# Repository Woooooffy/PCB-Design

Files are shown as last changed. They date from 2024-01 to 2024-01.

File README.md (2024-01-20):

# PCB-Design
# Contains my project files
# Hug-sensing IoT plush: a pair of plushies that detects hugs on one end and triggers response in the other. Inspired by Becky and Xyla's project https://beckystern.com/2023/11/27/hug-sensing-iot-parihug-toy-w-xyla-foxlin/ and part of the MIT 2024 PCB design class

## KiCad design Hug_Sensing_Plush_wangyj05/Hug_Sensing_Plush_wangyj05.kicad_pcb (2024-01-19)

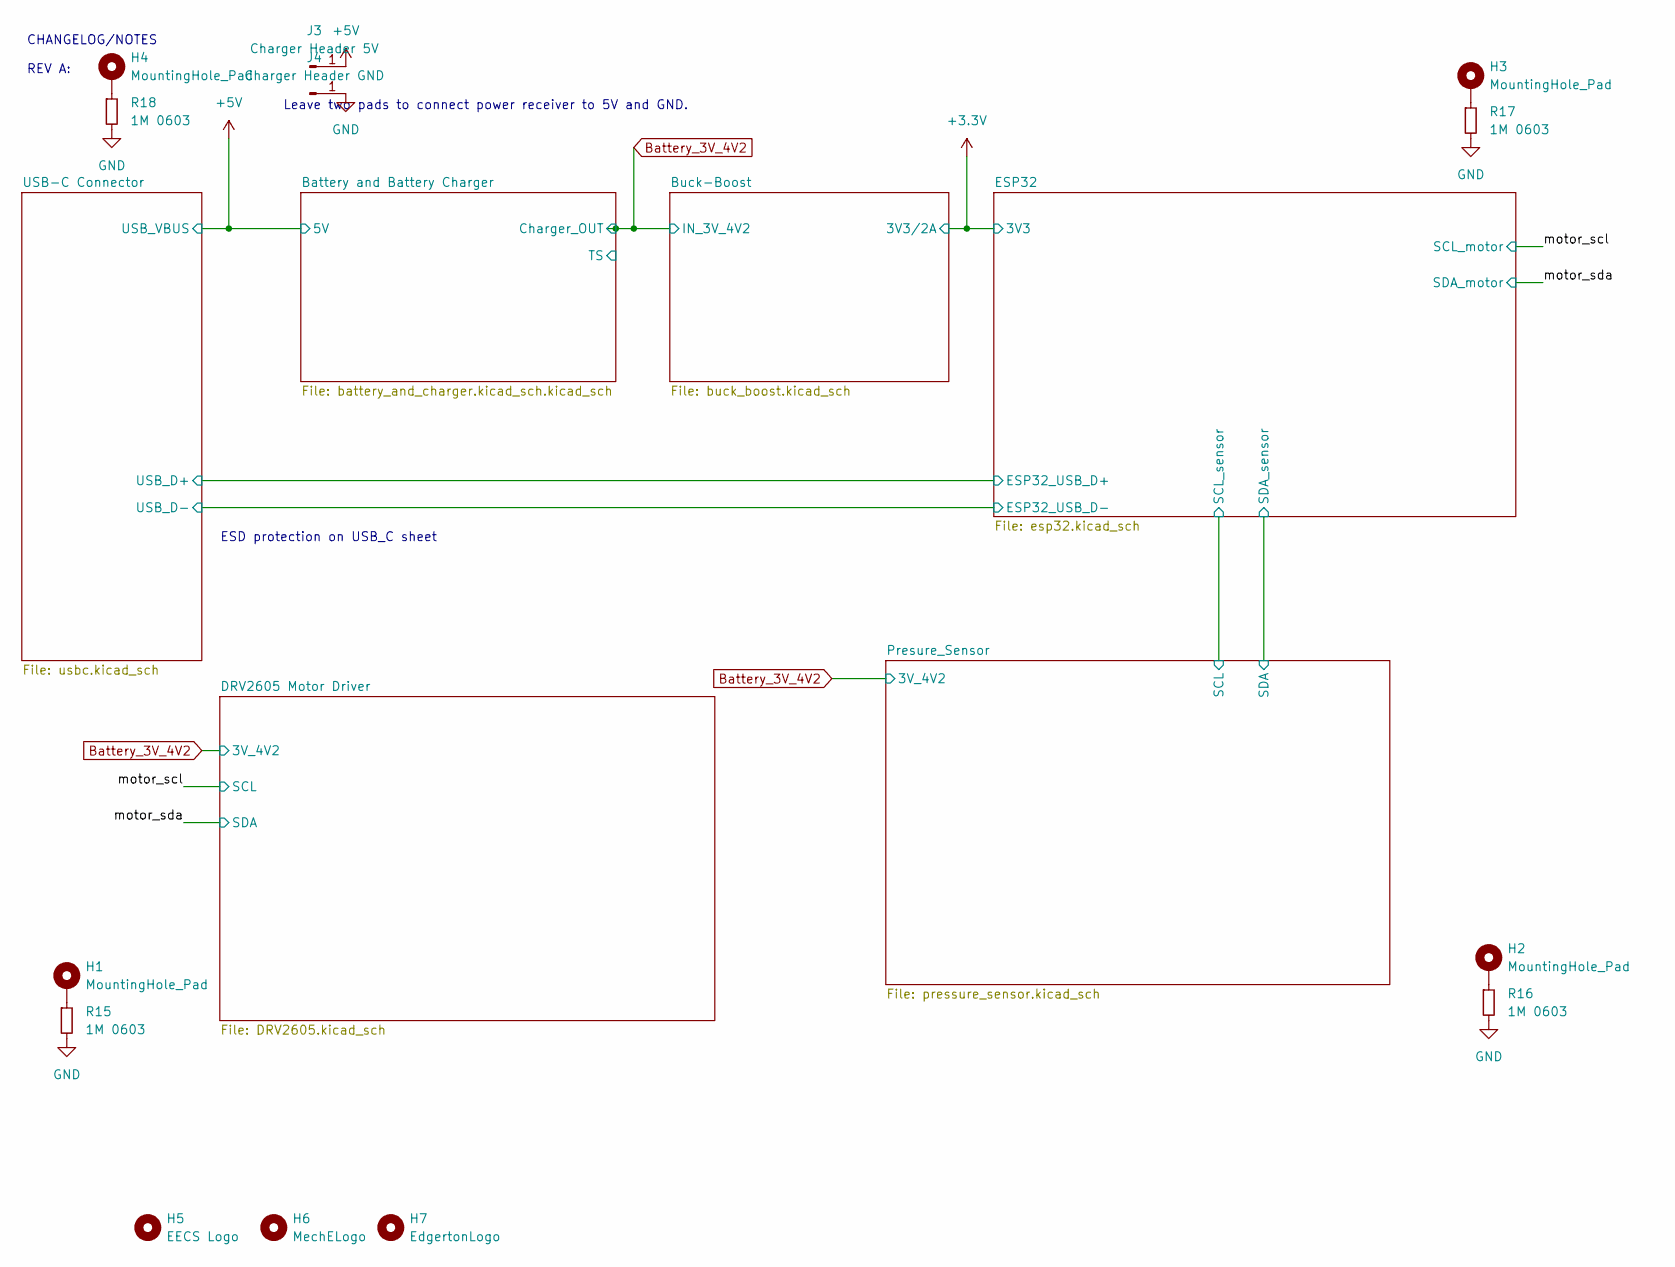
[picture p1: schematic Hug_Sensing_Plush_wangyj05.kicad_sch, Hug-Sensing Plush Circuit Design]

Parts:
H1, H2, H3, H4: MountingHole_Pad; MountingHole_2.2mm_M2_DIN965_Pad
H5: EECS Logo; EECSLogo
H6: MechELogo
H7: EdgertonLogo
J3: Charger Header 5V; SolderWirePad_1x01_SMD_1x2mm
J4: Charger Header GND; SolderWirePad_1x01_SMD_1x2mm
R15, R16, R17, R18: 1M 0603; R_0603_1608Metric_Pad0.98x0.95mm_HandSolder; MPN CRCW06031M00JNEAC; Digikey PN 541-CRCW06031M00JNEACCT-ND

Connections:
+5V: J3.1; also elsewhere on the board
GND: J4.1, R15.2, R16.2, R17.2, R18.2; also elsewhere on the board
unnamed: H1.1, R15.1
unnamed: H2.1, R16.1
unnamed: H3.1, R17.1
unnamed: H4.1, R18.1

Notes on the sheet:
ESD protection on USB_C sheet
Leave two pads to connect power receiver to 5V and GND.
CHANGELOG/NOTES REV A:

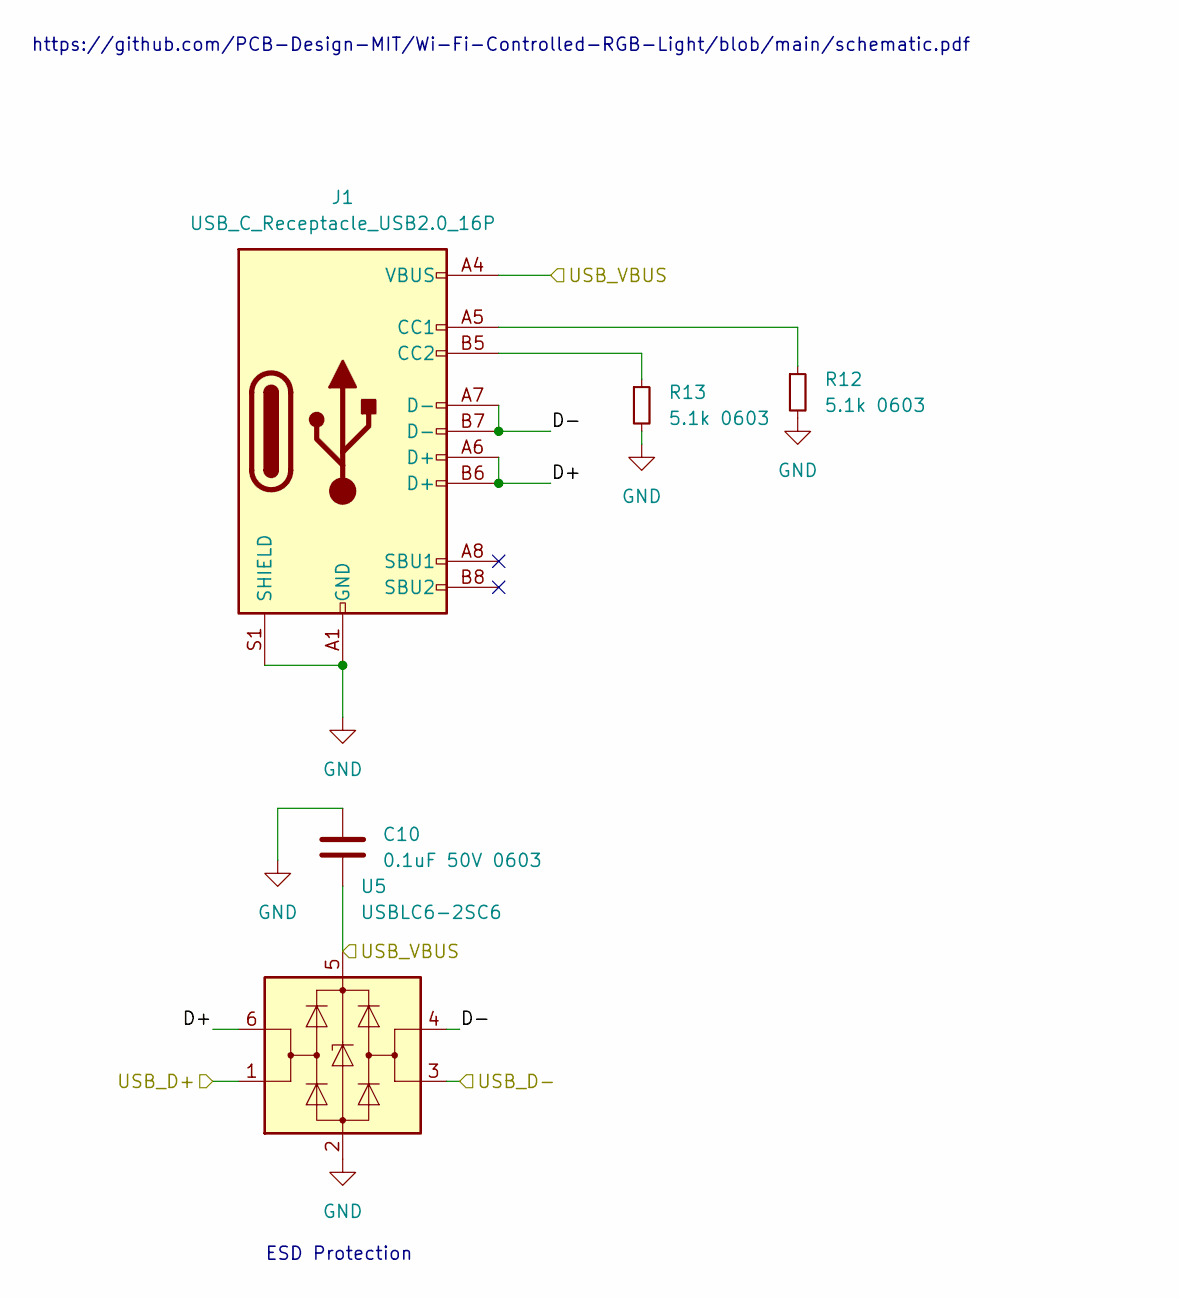
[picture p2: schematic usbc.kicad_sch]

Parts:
C10: 0.1uF 50V 0603; C_0603_1608Metric_Pad1.08x0.95mm_HandSolder; MPN CL10B104KB8NNNL; Digikey PN 1276-CL10B104KB8NNNLCT-ND
J1: USB_C_Receptacle_USB2.0_16P; USB_C_Receptacle_GCT_USB4085; MPN USB4085-GF-A; Digikey PN 2073-USB4085-GF-ACT-ND
R12, R13: 5.1k 0603; R_0603_1608Metric_Pad0.98x0.95mm_HandSolder; MPN CRCW06035K10FKEBC; Digikey PN 541-CRCW06035K10FKEBCDKR-ND
U5: USBLC6-2SC6; SOT-23-6; MPN USBLC6-2SC6; Digikey PN 497-5235-1-ND

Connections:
+5V: C10.2, J1.A4 (VBUS), J1.A9 (VBUS), J1.B4 (VBUS), J1.B9 (VBUS), U5.5 (VBUS); also elsewhere on the board
/ESP32/ESP32_USB_D+: U5.1 (I/O1); also elsewhere on the board
/ESP32/ESP32_USB_D-: U5.3 (I/O2); also elsewhere on the board
/USB-C Connector/D+: J1.A6 (D+), J1.B6 (D+), U5.6 (I/O1)
/USB-C Connector/D-: J1.A7 (D-), J1.B7 (D-), U5.4 (I/O2)
GND: C10.1, J1.A1 (GND), J1.A12 (GND), J1.B1 (GND), J1.B12 (GND), J1.S1 (SHIELD), R12.2, R13.2, U5.2 (GND); also elsewhere on the board
unnamed: J1.A5 (CC1), R12.1
unnamed: J1.B5 (CC2), R13.1

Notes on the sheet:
https://github.com/PCB-Design-MIT/Wi-Fi-Controlled-RGB-Light/blob/main/schematic.pdf
ESD Protection

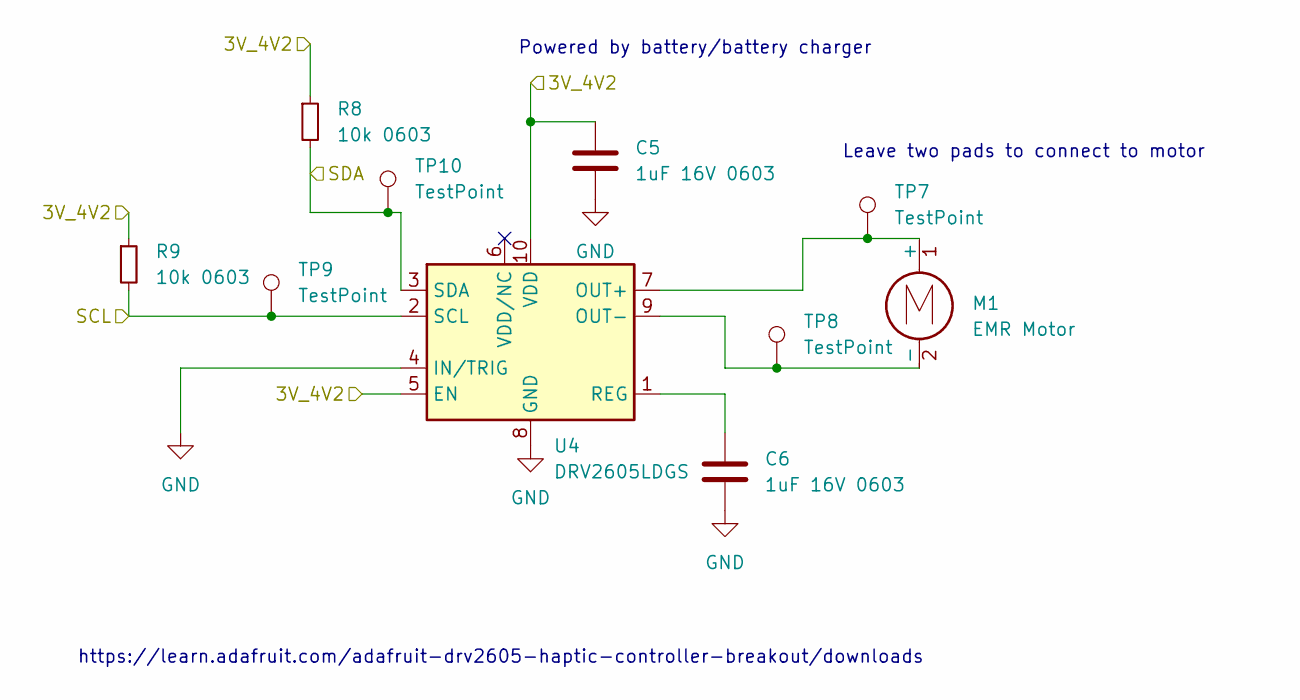
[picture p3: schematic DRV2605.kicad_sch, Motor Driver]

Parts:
C5, C6: 1uF 16V 0603; C_0603_1608Metric_Pad1.08x0.95mm_HandSolder; MPN CL10A105KO8NNNC; Digikey PN 1276-1034-1-ND
M1: EMR Motor; MPN 1201; Digikey PN 1528-1177-ND
R8, R9: 10k 0603; R_0603_1608Metric_Pad0.98x0.95mm_HandSolder; MPN CRCW060310K0FKEA; Digikey PN 541-10.0KHCT-ND
TP7, TP8, TP9, TP10: TestPoint; TestPoint_Keystone_5015_Micro-Minature; MPN RCWCTE; Digikey PN 2019-RCWCTECT-ND
U4: DRV2605LDGS; VSSOP-10_3x3mm_P0.5mm; MPN DRV2605LDGSR; Digikey PN 296-40032-1-ND

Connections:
/motor_scl: R9.2, TP9.1, U4.2 (SCL); also elsewhere on the board
/motor_sda: R8.2, TP10.1, U4.3 (SDA); also elsewhere on the board
Battery_3V_4V2: C5.1, R8.1, R9.1, U4.5 (EN), U4.10 (VDD); also elsewhere on the board
GND: C5.2, C6.2, U4.4 (IN/TRIG), U4.8 (GND); also elsewhere on the board
unnamed: M1.1 (+), TP7.1, U4.7 (OUT+)
unnamed: M1.2 (-), TP8.1, U4.9 (OUT-)
unnamed: C6.1, U4.1 (REG)

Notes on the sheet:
https://learn.adafruit.com/adafruit-drv2605-haptic-controller-breakout/downloads
Leave two pads to connect to motor
Powered by battery/battery charger

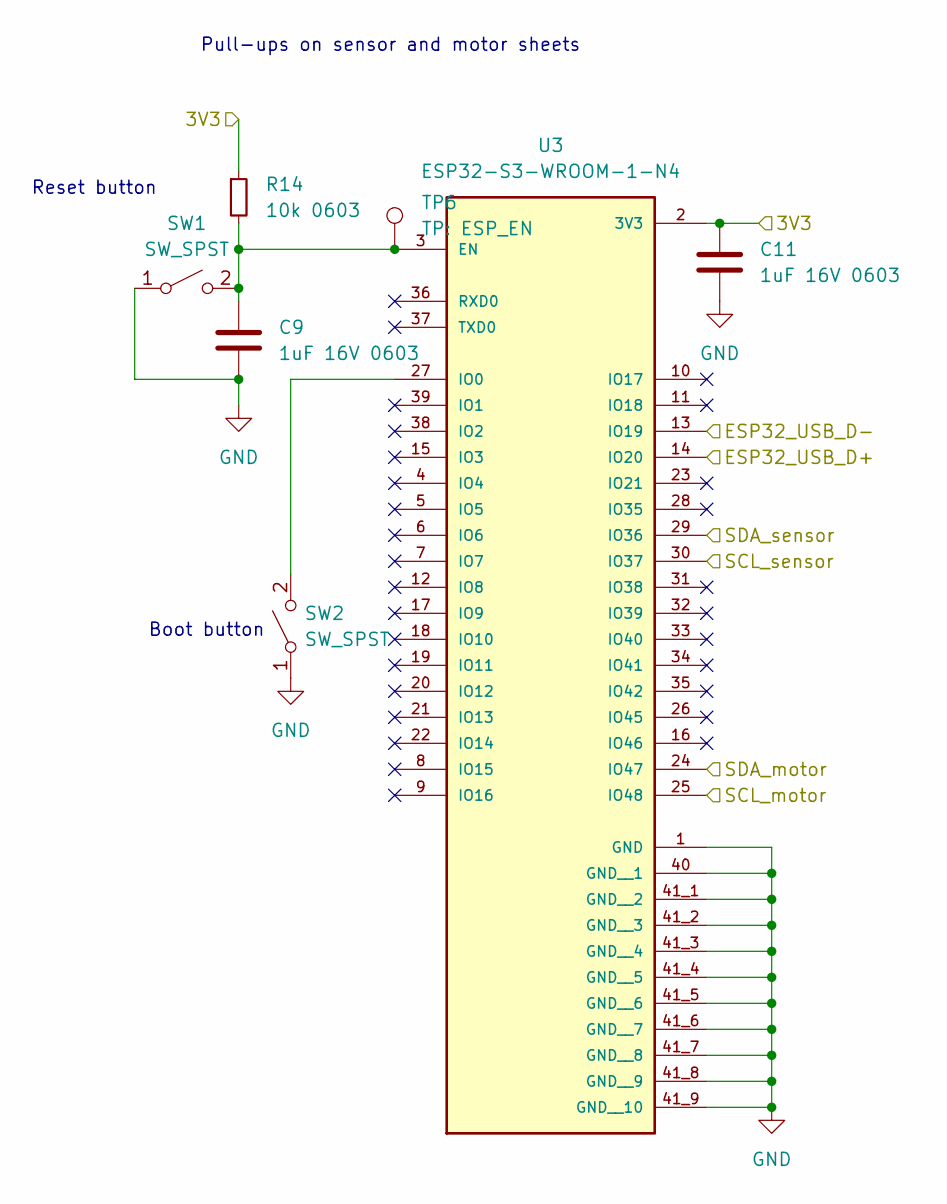
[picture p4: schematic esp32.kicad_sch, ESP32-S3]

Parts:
C9, C11: 1uF 16V 0603; C_0603_1608Metric_Pad1.08x0.95mm_HandSolder; MPN CL10A105KO8NNNC; Digikey PN 1276-1034-1-ND
R14: 10k 0603; R_0603_1608Metric_Pad0.98x0.95mm_HandSolder; MPN CRCW060310K0FKEA; Digikey PN 541-10.0KHCT-ND
SW1, SW2: SW_SPST; SW_SPST_FSMSM
TP6: TP: ESP_EN; TestPoint_Keystone_5015_Micro-Minature; MPN RCWCTE; Digikey PN 2019-RCWCTECT-ND
U3: ESP32-S3-WROOM-1-N4; ESP32-S3; PARTREV v1.0; Digikey PN 1965-ESP32-S3-WROOM-1-N4CT-ND

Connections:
+3.3V: C11.1, R14.1, U3.2 (3V3); also elsewhere on the board
/ESP32/ESP32_USB_D+: U3.14 (IO20); also elsewhere on the board
/ESP32/ESP32_USB_D-: U3.13 (IO19); also elsewhere on the board
/ESP32/SCL_sensor: U3.30 (IO37); also elsewhere on the board
/ESP32/SDA_sensor: U3.29 (IO36); also elsewhere on the board
/motor_scl: U3.25 (IO48); also elsewhere on the board
/motor_sda: U3.24 (IO47); also elsewhere on the board
GND: C9.2, C11.2, SW1.1 (A), SW2.1 (A), U3.1 (GND), U3.40 (GND__1), U3.41_1 (GND__2), U3.41_2 (GND__3), U3.41_3 (GND__4), U3.41_4 (GND__5), U3.41_5 (GND__6), U3.41_6 (GND__7), U3.41_7 (GND__8), U3.41_8 (GND__9), U3.41_9 (GND__10), U3.41_10, U3.41_11, U3.41_12, U3.41_13, U3.41_14, U3.41_15, U3.41_16, U3.41_17, U3.41_18, U3.41_19, U3.41_20, U3.41_21; also elsewhere on the board
unnamed: C9.1, R14.2, SW1.2 (B), TP6.1, U3.3 (EN)
unnamed: SW2.2 (B), U3.27 (IO0)

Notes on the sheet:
Pull-ups on sensor and motor sheets
Boot button
Reset button

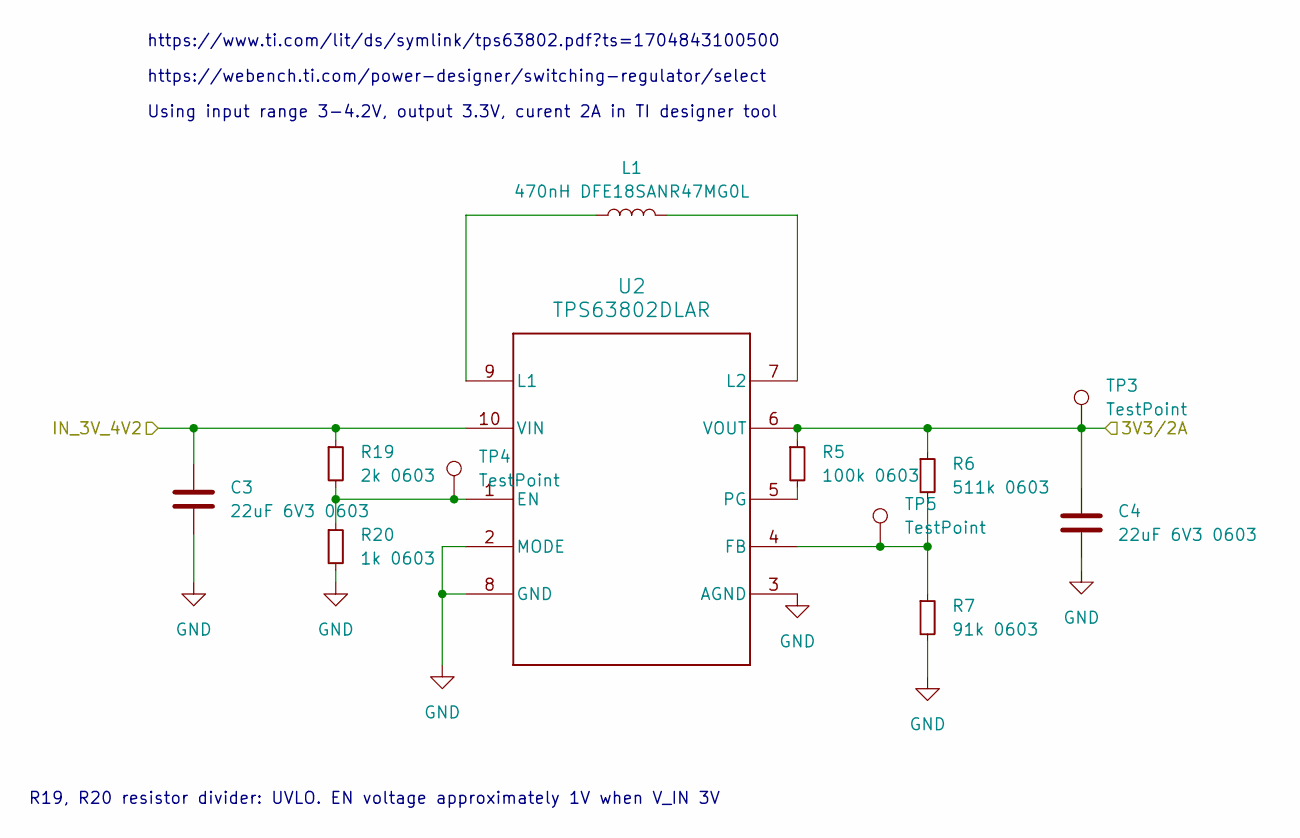
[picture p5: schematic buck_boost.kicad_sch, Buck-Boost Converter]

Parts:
C3, C4: 22uF 6V3 0603; C_0603_1608Metric_Pad1.08x0.95mm_HandSolder; MPN GRM188R60J226MEA0; Digikey PN 490-7612-2-ND
L1: 470nH DFE18SANR47MG0L; L_0603_1608Metric_Pad1.05x0.95mm_HandSolder; MPN DFE18SANR47MG0L; Digikey PN 490-16581-1-ND
R5: 100k 0603; R_0603_1608Metric_Pad0.98x0.95mm_HandSolder; MPN CRCW0603100KFKEA; Digikey PN 541-100KHCT-ND
R6: 511k 0603; R_0603_1608Metric_Pad0.98x0.95mm_HandSolder; MPN CRCW0603511KFKEA; Digikey PN 541-511KHCT-ND
R7: 91k 0603; R_0603_1608Metric_Pad0.98x0.95mm_HandSolder; MPN CRCW060391K0FKEAC; Digikey PN 541-5595-1-ND
R19: 2k 0603; R_0603_1608Metric_Pad0.98x0.95mm_HandSolder; MPN CRCW06032K00FKEB; Digikey PN 541-CRCW06032K00FKEBCT-ND
R20: 1k 0603; R_0603_1608Metric_Pad0.98x0.95mm_HandSolder; MPN CRCW06031K00FKEA; Digikey PN 541-1.00KHCT-ND
TP3, TP4, TP5: TestPoint; TestPoint_Keystone_5015_Micro-Minature; MPN RCWCTE; Digikey PN 2019-RCWCTECT-ND
U2: TPS63802DLAR; TPS63802; MPN TPS63802DLAR; Digikey PN 296-TPS63802DLARCT-ND

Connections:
+3.3V: C4.1, R5.1, R6.1, TP3.1, U2.6 (VOUT); also elsewhere on the board
Battery_3V_4V2: C3.1, R19.1, U2.10 (VIN); also elsewhere on the board
GND: C3.2, C4.2, R7.2, R20.2, U2.2 (MODE), U2.3 (AGND), U2.8 (GND); also elsewhere on the board
unnamed: R19.2, R20.1, TP4.1, U2.1 (EN)
unnamed: R6.2, R7.1, TP5.1, U2.4 (FB)
unnamed: L1.1, U2.9 (L1)
unnamed: L1.2, U2.7 (L2)
unnamed: R5.2, U2.5 (PG)

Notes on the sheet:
https://webench.ti.com/power-designer/switching-regulator/select
https://www.ti.com/lit/ds/symlink/tps63802.pdf?ts=1704843100500
R19, R20 resistor divider: UVLO. EN voltage approximately 1V when V_IN 3V
Using input range 3-4.2V, output 3.3V, curent 2A in TI designer tool

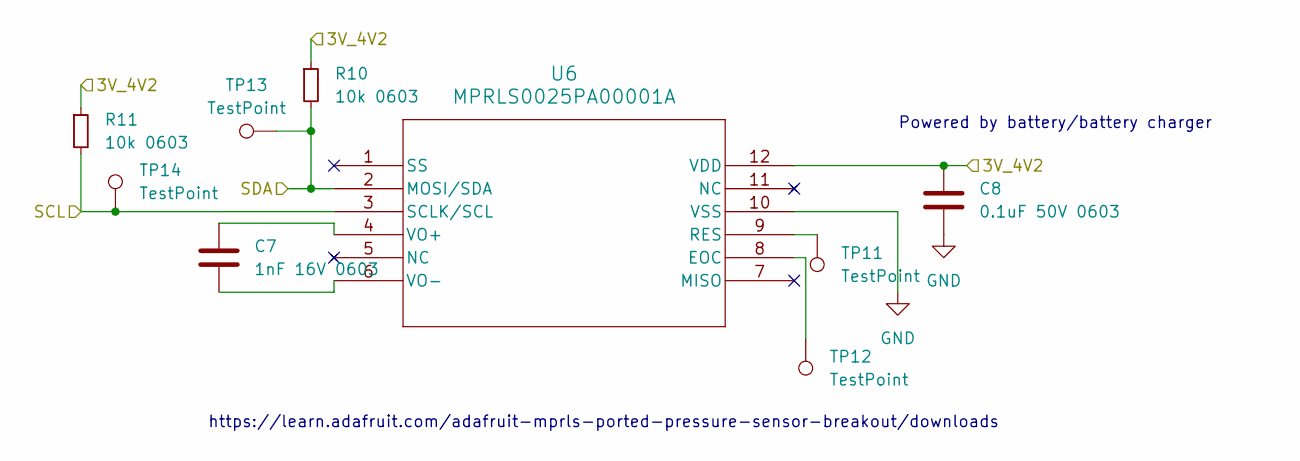
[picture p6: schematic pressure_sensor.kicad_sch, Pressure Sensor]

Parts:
C7: 1nF 16V 0603; C_0603_1608Metric_Pad1.08x0.95mm_HandSolder; MPN C0603C102K4RECAUTO; Digikey PN 399-17878-1-ND
C8: 0.1uF 50V 0603; C_0603_1608Metric_Pad1.08x0.95mm_HandSolder; MPN CL10B104KB8NNNL; Digikey PN 1276-CL10B104KB8NNNLCT-ND
R10, R11: 10k 0603; R_0603_1608Metric_Pad0.98x0.95mm_HandSolder; MPN CRCW060310K0FKEA; Digikey PN 541-10.0KHCT-ND
TP11, TP12, TP13, TP14: TestPoint; TestPoint_Keystone_5015_Micro-Minature; MPN RCWCTE; Digikey PN 2019-RCWCTECT-ND
U6: MPRLS0025PA00001A; MPRLS; MPN MPRLS0025PA00001A; Digikey PN 480-7098-1-ND

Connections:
/ESP32/SCL_sensor: R11.2, TP14.1, U6.3 (SCLK/SCL); also elsewhere on the board
/ESP32/SDA_sensor: R10.2, TP13.1, U6.2 (MOSI/SDA); also elsewhere on the board
Battery_3V_4V2: C8.1, R10.1, R11.1, U6.12 (VDD); also elsewhere on the board
GND: C8.2, U6.10 (VSS); also elsewhere on the board
unnamed: TP12.1, U6.8 (EOC)
unnamed: TP11.1, U6.9 (RES)
unnamed: C7.1, U6.4 (VO+)
unnamed: C7.2, U6.6 (VO-)

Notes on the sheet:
https://learn.adafruit.com/adafruit-mprls-ported-pressure-sensor-breakout/downloads
Powered by battery/battery charger

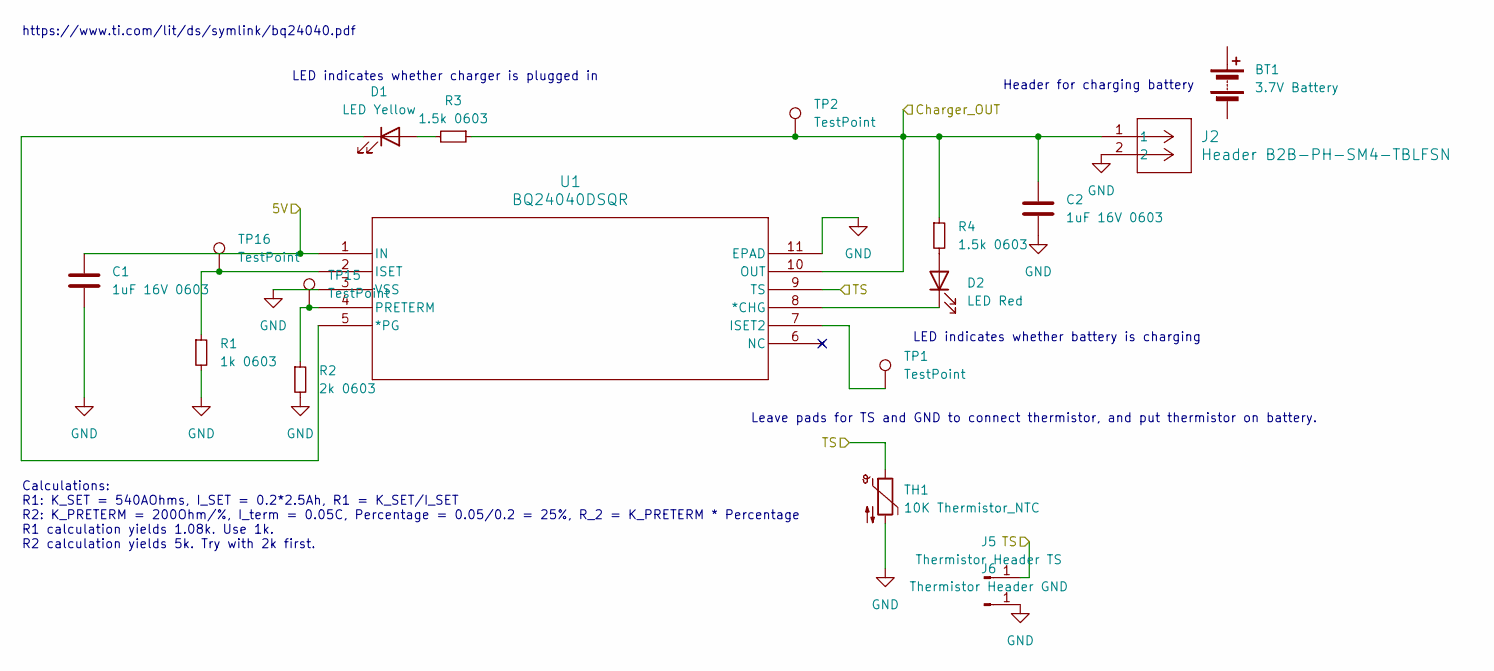
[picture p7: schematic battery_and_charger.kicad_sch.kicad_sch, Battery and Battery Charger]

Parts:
BT1: 3.7V Battery; MPN 328; Digikey PN 1528-1840-ND
C1, C2: 1uF 16V 0603; C_0603_1608Metric_Pad1.08x0.95mm_HandSolder; MPN CL10A105KO8NNNC; Digikey PN 1276-1034-1-ND
D1: LED Yellow; LED_0603_1608Metric_Pad1.05x0.95mm_HandSolder; MPN LTST-C190KSKT; Digikey PN 160-1437-1-ND
D2: LED Red; LED_0603_1608Metric_Pad1.05x0.95mm_HandSolder; MPN LTST-C190EKT; Digikey PN 160-1182-1-ND
J2: Header B2B-PH-SM4-TBLFSN; CONN_B2B-PH-SM4-TBLFSN_JST(Header); MPN B2B-PH-SM4-TB; Digikey PN 455-B2B-PH-SM4-TBCT-ND
J5: Thermistor Header TS; SolderWirePad_1x01_SMD_1x2mm
J6: Thermistor Header GND; SolderWirePad_1x01_SMD_1x2mm
R1: 1k 0603; R_0603_1608Metric_Pad0.98x0.95mm_HandSolder; MPN CRCW06031K00FKEA; Digikey PN 541-1.00KHCT-ND
R2: 2k 0603; R_0603_1608Metric_Pad0.98x0.95mm_HandSolder; MPN CRCW06032K00FKEB; Digikey PN 541-CRCW06032K00FKEBCT-ND
R3, R4: 1.5k 0603; R_0603_1608Metric_Pad0.98x0.95mm_HandSolder; MPN CRCW06031K50FKEB; Digikey PN 541-CRCW06031K50FKEBCT-ND
TH1: 10K Thermistor_NTC; MPN 4890; Digikey PN 1528-4890-ND
TP1, TP2, TP15, TP16: TestPoint; TestPoint_Keystone_5015_Micro-Minature; MPN RCWCTE; Digikey PN 2019-RCWCTECT-ND
U1: BQ24040DSQR; BQ24040; MPN BQ24040DSQR; Digikey PN 296-37142-1-ND

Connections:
+5V: C1.1, U1.1 (IN); also elsewhere on the board
/Battery and Battery Charger/TS: J5.1, TH1.1, U1.9 (TS)
Battery_3V_4V2: C2.1, J2.1, R3.1, R4.1, TP2.1, U1.10 (OUT); also elsewhere on the board
GND: C1.2, C2.2, J2.2, J2.3, J2.4, J6.1, R1.2, R2.2, TH1.2, U1.3 (VSS), U1.11 (EPAD), U1.V; also elsewhere on the board
unnamed: D1.2 (A), R3.2
unnamed: D1.1 (K), U1.5 (*PG)
unnamed: D2.2 (A), R4.2
unnamed: D2.1 (K), U1.8 (*CHG)
unnamed: TP1.1, U1.7 (ISET2)
unnamed: R1.1, TP16.1, U1.2 (ISET)
unnamed: R2.1, TP15.1, U1.4 (PRETERM)

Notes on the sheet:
Header for charging battery
LED indicates whether battery is charging
Leave pads for TS and GND to connect thermistor, and put thermistor on battery.
Calculations: R1: K_SET = 540AOhms, I_SET = 0.2*2.5Ah, R1 = K_SET/I_SET R2: K_PRETERM = 200Ohm/%, I_term = 0.05C, Percentage = 0.05/0.2 = 25%, R_2 = K_PRETERM * Percentage R1 calculation yields 1.08k. Use 1k. R2 calculation yields 5k. Try with 2k first.
https://www.ti.com/lit/ds/symlink/bq24040.pdf
LED indicates whether charger is plugged in

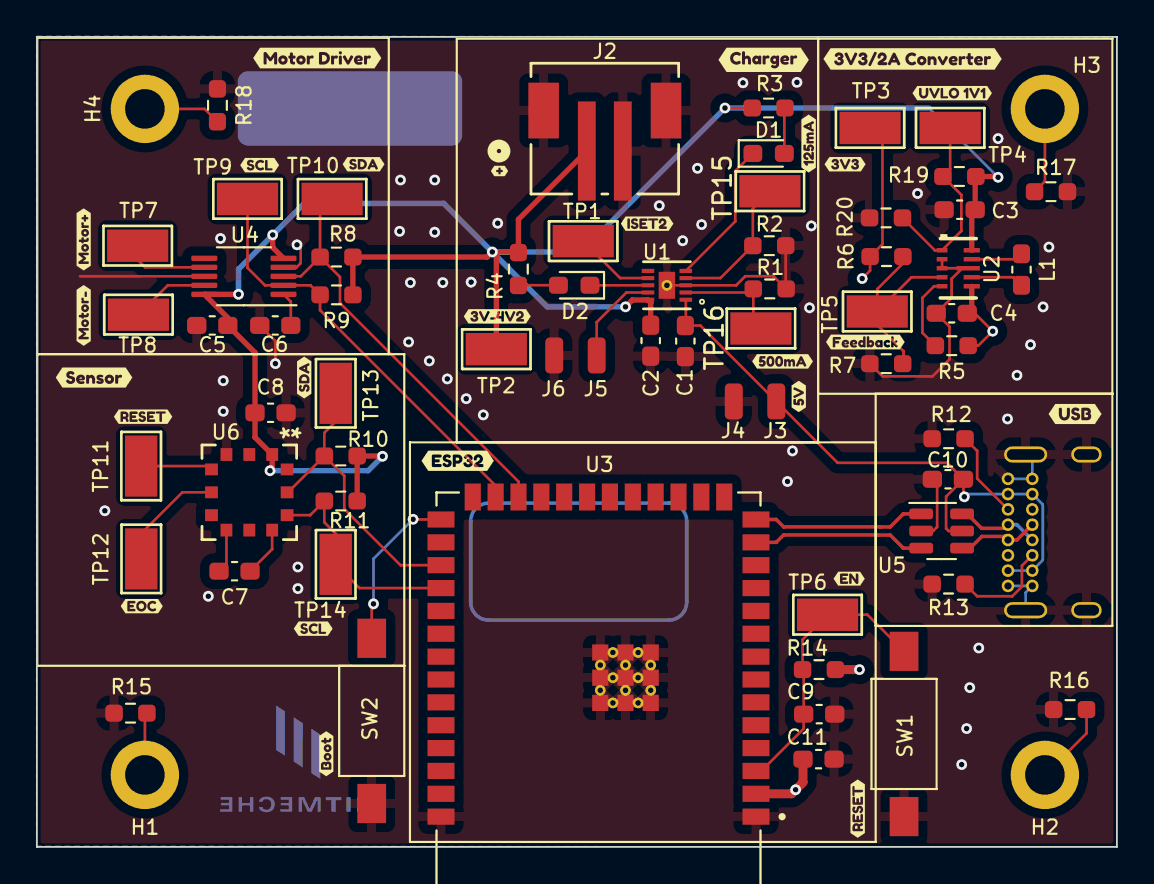
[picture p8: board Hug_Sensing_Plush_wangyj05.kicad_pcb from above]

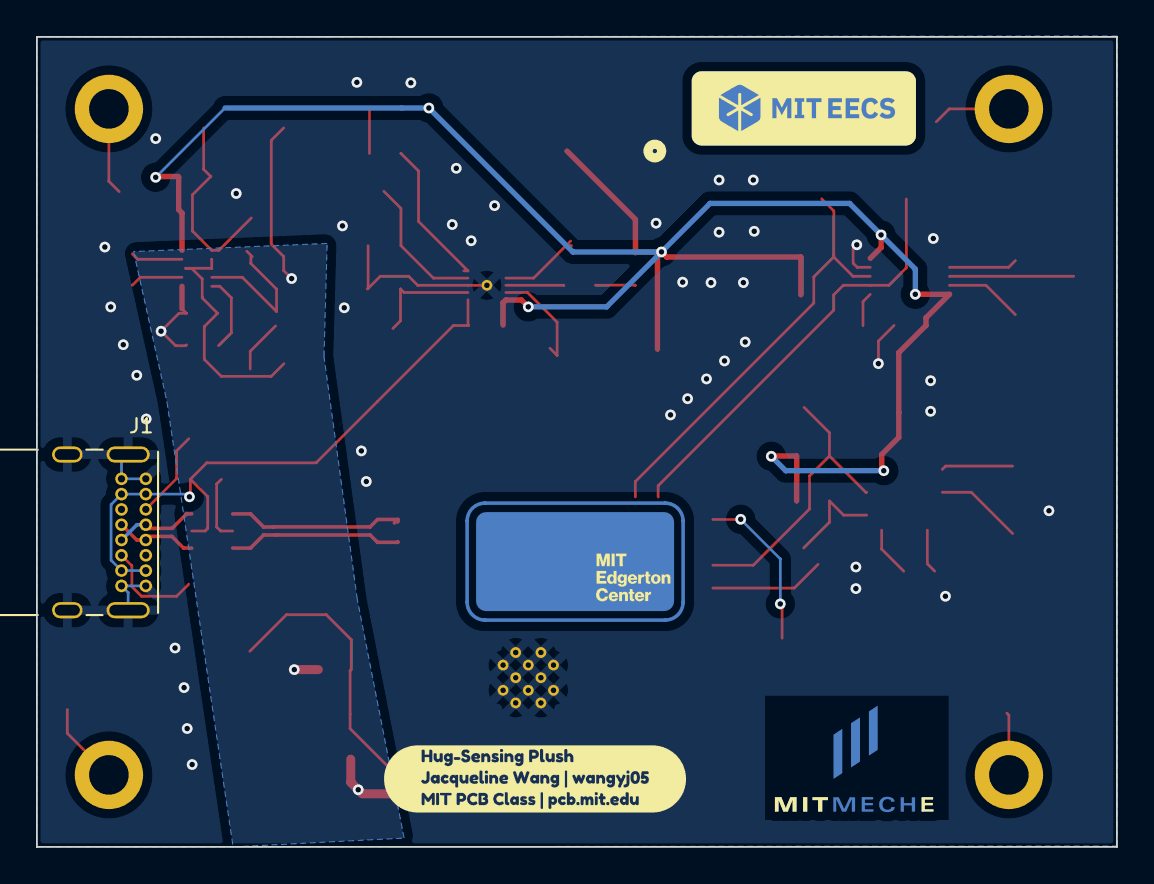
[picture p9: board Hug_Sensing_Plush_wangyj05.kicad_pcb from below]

Board: 2 copper layers, 60.0 x 45.0 mm, 98 parts (5 on the bottom side), 40 nets.

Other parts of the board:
kibuzzard-65AAE9C3: G***; kibuzzard-65AAE9C3
kibuzzard-65AAE9E5: G***; kibuzzard-65AAE9E5
kibuzzard-65AAEA4C: G***; kibuzzard-65AAEA4C
kibuzzard-65AAEA37: G***; kibuzzard-65AAEA37
kibuzzard-65AAEA43: G***; kibuzzard-65AAEA43
kibuzzard-65AAEA55: G***; kibuzzard-65AAEA55
kibuzzard-65AAEA96: G***; kibuzzard-65AAEA96
kibuzzard-65AAEAAB: G***; kibuzzard-65AAEAAB
kibuzzard-65AAEAD5: G***; kibuzzard-65AAEAD5
kibuzzard-65AAEADF: G***; kibuzzard-65AAEADF
kibuzzard-65AAEB64: G***; kibuzzard-65AAEB64
kibuzzard-65AAEBD9: G***; kibuzzard-65AAEBD9
kibuzzard-65AAEBEE: G***; kibuzzard-65AAEBEE
kibuzzard-65AAECF1: G***; kibuzzard-65AAECF1
kibuzzard-65AAF1CD: G***; kibuzzard-65AAF1CD
kibuzzard-65AAF1FE: G***; kibuzzard-65AAF1FE
kibuzzard-65AAF2C1: G***; kibuzzard-65AAF2C1
kibuzzard-65AAF2E5: G***; kibuzzard-65AAF2E5
kibuzzard-65AAF3AD: G***; kibuzzard-65AAF3AD
kibuzzard-65AAF7C7: G***; kibuzzard-65AAF7C7
kibuzzard-65AAF38A: G***; kibuzzard-65AAF38A
kibuzzard-65AAF39C: G***; kibuzzard-65AAF39C
kibuzzard-65AAF250: G***; kibuzzard-65AAF250
kibuzzard-65AAF270: G***; kibuzzard-65AAF270
kibuzzard-65AAF304: G***; kibuzzard-65AAF304
kibuzzard-65AAF374: G***; kibuzzard-65AAF374
kibuzzard-65AAF394: G***; kibuzzard-65AAF394

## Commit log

2024-01-15 Hug sensing plush design with KiCAD
    [DRV2605.kicad_sch, Hug_Sensing_Plush_wangyj05.kicad_pcb, Hug_Sensing_Plush_wangyj05.kicad_sch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]
2024-01-16 Hug-Sensing IoT Plush
    [Hug_Sensing_Plush_wangyj05.kicad_pcb, usbc.kicad_sch]
2024-01-16 Removed some files
    [Lab01_wangyj05.kicad_pcb, Lab01_wangyj05.kicad_sch]
2024-01-16 Lab01 Files
    [Lab01_wangyj05.kicad_pcb, Lab01_wangyj05.kicad_sch]
2024-01-17 Edited board layout
    [Hug_Sensing_Plush_wangyj05.kicad_pcb, Hug_Sensing_Plush_wangyj05.kicad_sch, battery_and_charger.kicad_sch.kicad_sch]
2024-01-18 Updated layout
    [Hug_Sensing_Plush_wangyj05.kicad_pcb, Hug_Sensing_Plush_wangyj05.kicad_sch, battery_and_charger.kicad_sch.kicad_sch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]
2024-01-19 Edited PCB layout
    [Hug_Sensing_Plush_wangyj05.kicad_pcb, esp32.kicad_sch]
2024-01-19 Updated board layout
    [Hug_Sensing_Plush_wangyj05.kicad_pcb, Hug_Sensing_Plush_wangyj05.kicad_sch, battery_and_charger.kicad_sch.kicad_sch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]
2024-01-20 Edited file names
    [Lab01_wangyj05.kicad_pcb, Lab01_wangyj05.kicad_sch]
2024-01-27 Added more references
    [DRV2605.kicad_sch, pressure_sensor.kicad_sch]
